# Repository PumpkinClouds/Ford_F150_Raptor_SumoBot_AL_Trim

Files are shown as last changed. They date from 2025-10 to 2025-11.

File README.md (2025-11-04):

# Ford_F150_Raptor_SumoBot_AL_Trim
Sumo Bot Designed by Minh Nguyen, David Hong, Nathan Wignall, and Ana Wise

This Repository contains the code and pcb design for the sumo bot.

The "Ford F150" is a unique 4 wheeled sumo bot

PCB Design Software: KiCad

Microcontroller used: STM32F303CCT6 ([datasheet]([url](https://www.st.com/content/ccc/resource/technical/document/datasheet/f2/1f/e1/41/ef/59/4d/50/DM00058181.pdf/files/DM00058181.pdf/jcr:content/translations/en.DM000581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)))

Microcontroller Programming Framework: 

3 IR Distance Sensors: Adafruit GP2Y0A21YK0F [Link]([url](https://www.adafruit.com/product/164)) 

4 JSumo ML1 Line Sensors: JSumo JS16249 [Link]([url](https://www.jsumo.com/micro-line-sensor-ml1))

Bot code and pcb for sumo bot competition. (Asgore's fault)

## Contributing to the Project

### Software Dependencies
- [ ] KiCAD
- [ ] A text editor
- [ ] (Optional) Nix + Flakes + Direnv, automatically sets up a development enviornment to work on the project with

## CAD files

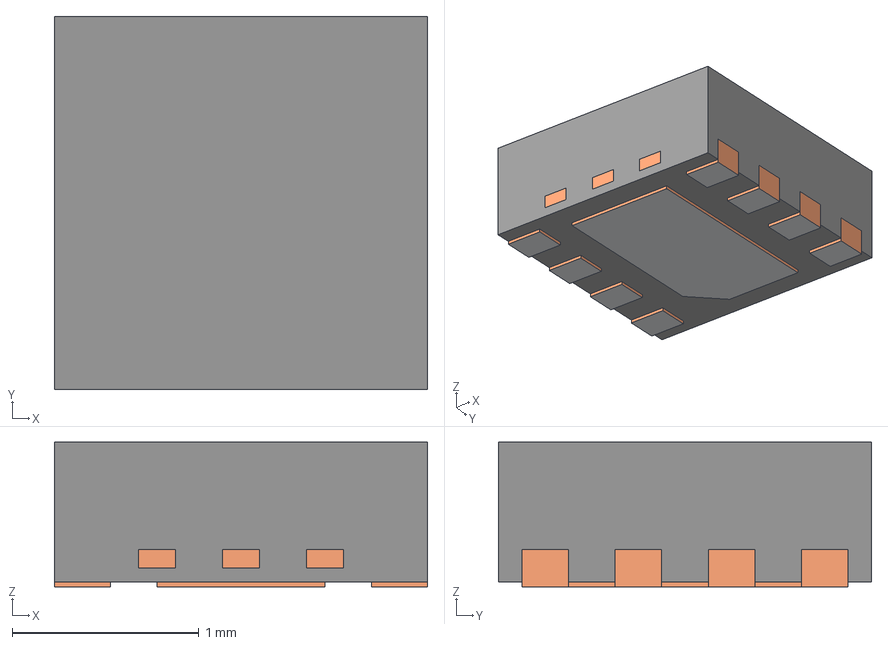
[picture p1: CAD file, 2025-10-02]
KiCAD/BrainBoard/3d-models/DRV8231DSGR.stp
2.00 x 2.00 x 0.775 mm
BODY-SON
FRAME-DSG0008A
PIN1-ID

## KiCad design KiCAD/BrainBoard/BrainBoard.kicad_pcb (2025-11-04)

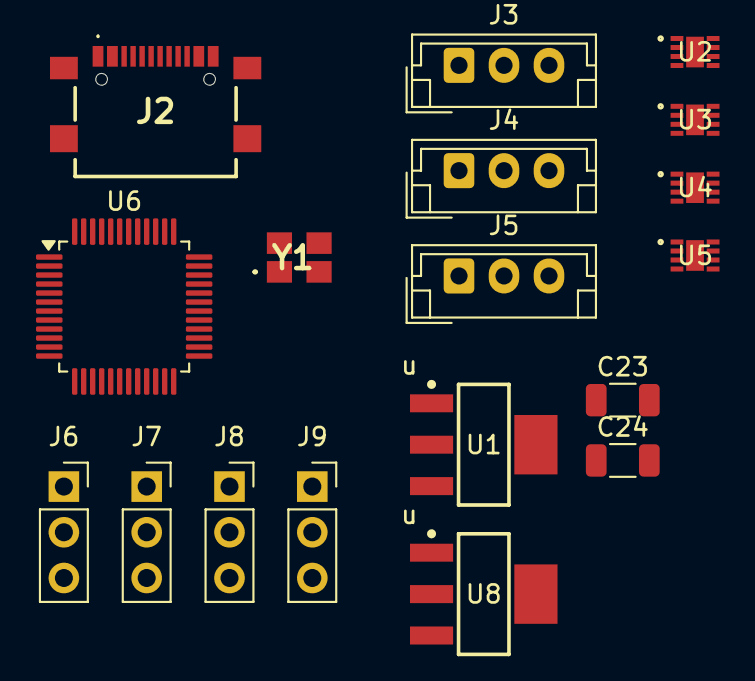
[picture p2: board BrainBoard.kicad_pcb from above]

Board: 2 copper layers, 18 parts (0 on the bottom side), 25 nets, no tracks yet.

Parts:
C23: 0.47uF; C_1206_3216Metric
C24: 22uF; C_1206_3216Metric
J2: USB4216-03-A; USB421603A
J3, J4, J5: Conn_01x03_Socket; JST_EH_B3B-EH-A_1x03_P2.50mm_Vertical
J6, J7, J8, J9: Conn_01x03_Socket; PinSocket_1x03_P2.54mm_Vertical
U1: TLV1117-33; DCY0004A_N
U2, U3, U4, U5: DRV8231DSGR; WSON8_DRV8231_TEX
U6: STM32F303CCTx; LQFP-48_7x7mm_P0.5mm
U8: LM2940IMPX-5.0/NOPB; DCY0004A_N
Y1: NX3225SA-32.000MHZ-STD-CSR-1; NX3225SA32000MHZSTDCSR1

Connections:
+3.3V: J6.2, J7.2, J8.2, J9.2, U1.2 (VO), U2.4 (VREF), U3.4 (VREF), U4.4 (VREF), U5.4 (VREF), U6.1 (VBAT), U6.24 (VDD), U6.36 (VDD), U6.48 (VDD)
+5V: J3.1, J4.1, J5.1
+BATT: C23.1, U1.3 (VI), U2.5 (VM), U3.5 (VM), U4.5 (VM), U5.5 (VM), U8.1 (IN)
/Distance Sensors/DIST_SENS_1: J3.3, U6.21 (PB10)
/Distance Sensors/DIST_SENS_2: J4.3, U6.25 (PB12)
/Distance Sensors/DIST_SENS_3: J5.3, U6.26 (PB13)
/Line Sensors/LINE_1: J6.1, U6.13 (PA3)
/Line Sensors/LINE_2: J7.1, U6.19 (PB1)
/Line Sensors/LINE_3: J8.1, U6.38 (PA15)
/Line Sensors/LINE_4: J9.1, U6.45 (PB8)
/Motor Drivers/IN1_A: U3.3 (IN1), U6.11 (PA1)
/Motor Drivers/IN1_B: U2.3 (IN1), U6.16 (PA6)
/Motor Drivers/IN1_C: U4.3 (IN1), U6.43 (PB7)
/Motor Drivers/IN1_D: U5.3 (IN1), U6.27 (PB14)
/Motor Drivers/IN2_A: U3.2 (IN2), U6.12 (PA2)
/Motor Drivers/IN2_B: U2.2 (IN2), U6.17 (PA7)
/Motor Drivers/IN2_C: U4.2 (IN2), U6.42 (PB6)
/Motor Drivers/IN2_D: U5.2 (IN2), U6.28 (PB15)
/STM32F303CCT6 Microcontroller/HSE_IN: U6.5 (PF0), Y1.1 (XTAL_1)
/STM32F303CCT6 Microcontroller/HSE_OUT: U6.6 (PF1), Y1.3 (XTAL_2)
/STM32F303CCT6 Microcontroller/USB_D+: J2.A6 (DP1), J2.B6 (DP2), U6.33 (PA12)
/STM32F303CCT6 Microcontroller/USB_D-: J2.A7 (DN1), J2.B7 (DN2), U6.32 (PA11)
/STM32F303CCT6 Microcontroller/USB_VBUS: J2.A4 (VBUS_1), J2.B4 (VBUS_2)
/Voltage Regulator/5V: C24.1, U8.3 (OUT)
GND: C23.2, C24.2, J2.A1 (GND_1), J2.B1 (GND_2), J2.G1 (GND_3), J2.G2 (GND_4), J2.G3 (GND_5), J2.G4 (GND_6), J3.2, J4.2, J5.2, J6.3, J7.3, J8.3, J9.3, U1.1 (GND), U6.8 (VSSA), U6.23 (VSS), U6.35 (VSS), U6.47 (VSS), Y1.2 (GND_1), Y1.4 (GND_2)

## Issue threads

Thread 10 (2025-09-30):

Discuss Motor Driver Current Sensing

nathan-jw, 2025-09-30:
The DRV8231ADSG features an optional current sensing pin (IPROPI)

Decide whether to:
1. Tie these to GND to disable them
2. Attach each of them to a GPIO pin
3. Come up with some mechanism to switch between 1 and 2

Disabling will also disable current regulation (usually)

Alternatively, we could use something like the [DRV88703.6-A](https://www.ti.com/lit/ds/slvscy8b/slvscy8b.pdf?ts=1759206506602) if we don't think we need external current sensing or regulation

nathan-jw, 2025-10-02:
Don't need external current sensing, going with the [DRV8231DSGR](https://www.digikey.com/en/products/detail/texas-instruments/DRV8231DSGR/15853798)

Closed 2025-10-02.

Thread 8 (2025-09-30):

Motor Drivers

nathan-jw, 2025-09-30:
[DRV8231ADSGR](https://www.digikey.com/en/products/detail/texas-instruments/drv8231adsgr/15853799)

nathan-jw, 2025-09-30:
actually DRV8231ADSGR

nathan-jw, 2025-09-30:
77232b6e59e7cf0e1b83ac898a83cdbea52ad8b0

nathan-jw, 2025-10-02:
Switching to the [DRV8231DSGR](https://www.digikey.com/en/products/detail/texas-instruments/DRV8231DSGR/15853798)

Closed 2025-10-02.

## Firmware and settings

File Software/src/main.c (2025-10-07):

#include <libopencm3/stm32/gpio.h>
#include <libopencm3/stm32/rcc.h>

/* Set STM32 to 64 MHz. */
static void clock_setup(void) {
    rcc_clock_setup_hsi(&rcc_hsi_configs[RCC_CLOCK_HSI_64MHZ]);
}

/**
 * Set the GPIO pins of the microcontroller
 */
static void gpio_setup(void) {
    // Enable clocks for GPIO Ports
    rcc_periph_clock_enable(RCC_GPIOE);

    /* Set GPIO12 (in GPIO port D) to 'output push-pull'. */
    gpio_mode_setup(
        GPIOE, GPIO_MODE_OUTPUT, GPIO_PUPD_NONE, GPIO8 | GPIO9 | GPIO10 | GPIO11
    );
}

int main(void) {
    clock_setup();
    gpio_setup();

    while (1) {}

    return 0;
}

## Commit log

2025-09-29 kicad files
    [BrainBoard.kicad_pcb, BrainBoard.kicad_sch]
2025-09-29 refactor: adding some dev files and reorganizing file structure
    [BrainBoard.kicad_pcb, BrainBoard.kicad_sch]
2025-09-30 add folders for footprints, symbols, and 3d-models
2025-09-30 [feat] add voltage regulator
    [BrainBoard.kicad_sch, LM2940x.stp, voltage_regulator.kicad_sch]
2025-09-30 [bug] make ERC happy
    [BrainBoard.kicad_pcb, BrainBoard.kicad_sch, voltage_regulator.kicad_sch]
2025-09-30 [docs] update page settings
    [BrainBoard.kicad_sch, voltage_regulator.kicad_sch]
2025-09-30 [fix] replace linear regulator
    [LM2940x.stp, voltage_regulator.kicad_sch]
2025-09-30 [feat] add example motor driver
    [BrainBoard.kicad_sch, motor_drivers.kicad_sch, voltage_regulator.kicad_sch]
2025-10-02 [feature] Finalize DRV8231DSGR motor drivers
    [BrainBoard.kicad_sch, DRV8231DSGR.stp, motor_driver.json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]
2025-10-06 feat: Processor add
    [BrainBoard.kicad_sch, DRV8231DSGR.stp, Microcontroller.kicad_sch]
2025-10-06 fix: Make DRC happy
    [BrainBoard.kicad_sch, Microcontroller.kicad_sch, motor_drivers.kicad_sch]
2025-10-07 refactor(Software): change the PIO framework to `libopencm3`
2025-10-07 feat(KiCad): Add a .gitignore for KiCad project
2025-10-13 feat: add second battery
    [BrainBoard.kicad_sch]
2025-10-18 Added and finalized GPIO and PWM pinouts
    [Microcontroller.kicad_sch]
2025-10-18 feat: added hierarchy pins to global sheet
    [BrainBoard.kicad_sch]
2025-10-20 feat: Connect microcontroller pwm signals into motor drivers
    [BrainBoard.kicad_sch]
2025-10-20 feat: battery input
    [BrainBoard.kicad_sch, Microcontroller.kicad_sch, motor_drivers.kicad_sch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]
2025-10-20 fix: correct nominal voltage
    [BrainBoard.kicad_sch]
2025-10-28 feat: added hiearchal power pins to microcontroller to avoid having global labels in hiearchal sheets
    [BrainBoard.kicad_sch, Microcontroller.kicad_sch]
2025-10-28 feat: added micro-jst connector pins for distance sensors
    [BrainBoard.kicad_sch, distance_sensors.kicad_sch, line_sensors.kicad_sch]
2025-11-03 feat: Line sensor thing push
    [BrainBoard.kicad_sch, line_sensors.kicad_sch]
2025-11-04 feat: add +5V line
    [BrainBoard.kicad_pcb, BrainBoard.kicad_sch, Microcontroller.kicad_sch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]
2025-11-04 Assigned most general footprints
    [BrainBoard.kicad_sch, Microcontroller.kicad_sch, motor_drivers.kicad_sch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]
